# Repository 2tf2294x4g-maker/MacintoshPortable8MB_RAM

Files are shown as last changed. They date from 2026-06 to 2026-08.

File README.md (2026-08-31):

# Mac Portable 8MB RAM Card (v2 — All-5V)

Expands a Macintosh Portable to **9 MB total** (1 MB onboard + 8 MB this card) — the maximum the Portable's address space supports.

All-5V design using 1M×8 SRAM chips. No level shifters, no LDO regulator, no 3.3V rail. Shares the same connector, CPLD, and bus transceiver approach as the [4MB card](https://github.com/2tf2294x4g-maker/MacintoshPortable4MB_RAM) but doubles capacity using larger SRAM.

> ✅ **HARDWARE VALIDATED** — Built and tested on a Mac Portable M5120 (July 2026). Boots reliably, passes 9 MB in About This Macintosh, and with the DTACK bodge (see below) outperforms the 1 MB baseline.

---

## Photos

| | |
|---|---|
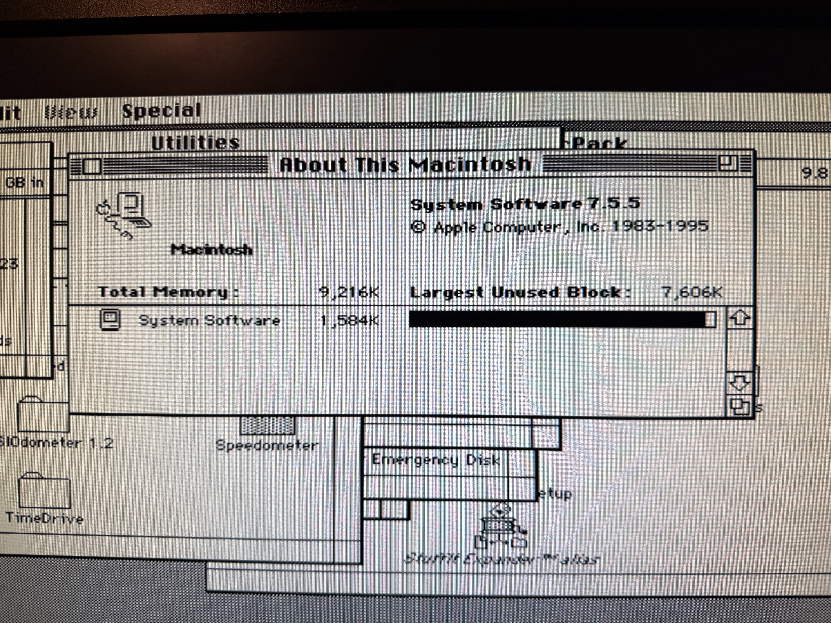
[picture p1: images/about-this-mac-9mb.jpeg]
About This Macintosh showing 9,216K
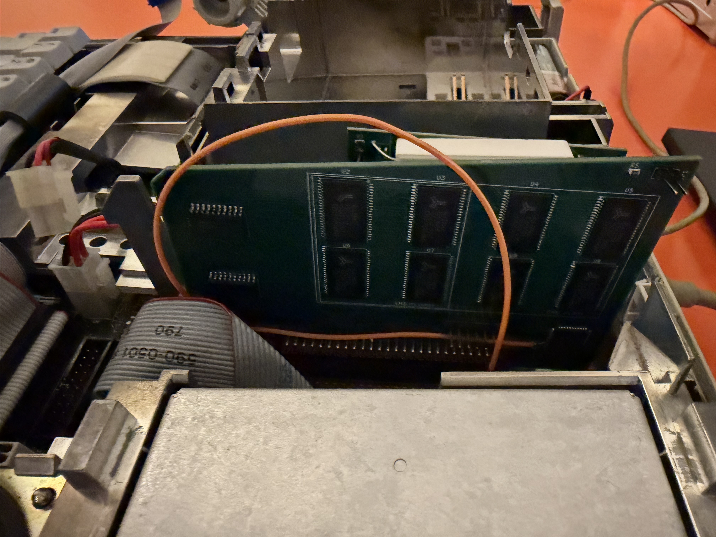
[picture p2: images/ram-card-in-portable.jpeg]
RAM card installed in Mac Portable with DTACK bodge wire
|  |  |
| System 7.5.5 — 9,216K total memory | Card seated in Portable with orange DTACK bodge wire |

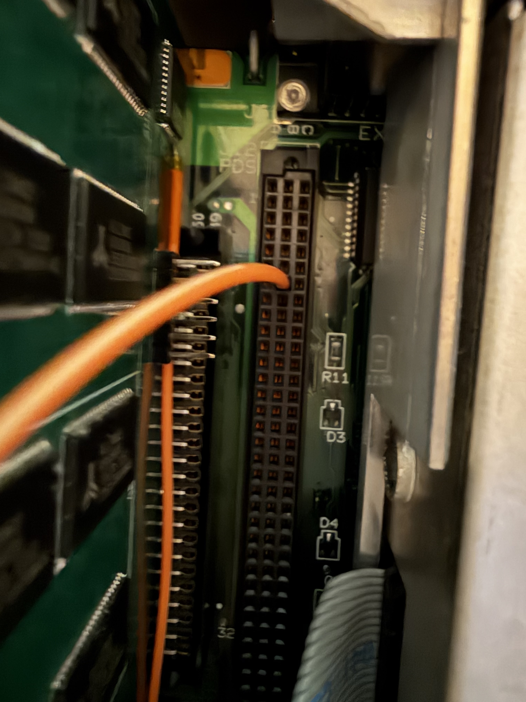
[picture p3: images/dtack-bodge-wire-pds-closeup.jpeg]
Close-up of DTACK bodge wire at PDS connector

*Orange bodge wire running from CPLD pin 42 to PDS slot pin B7 (/DTACK)*

| | |
|---|---|
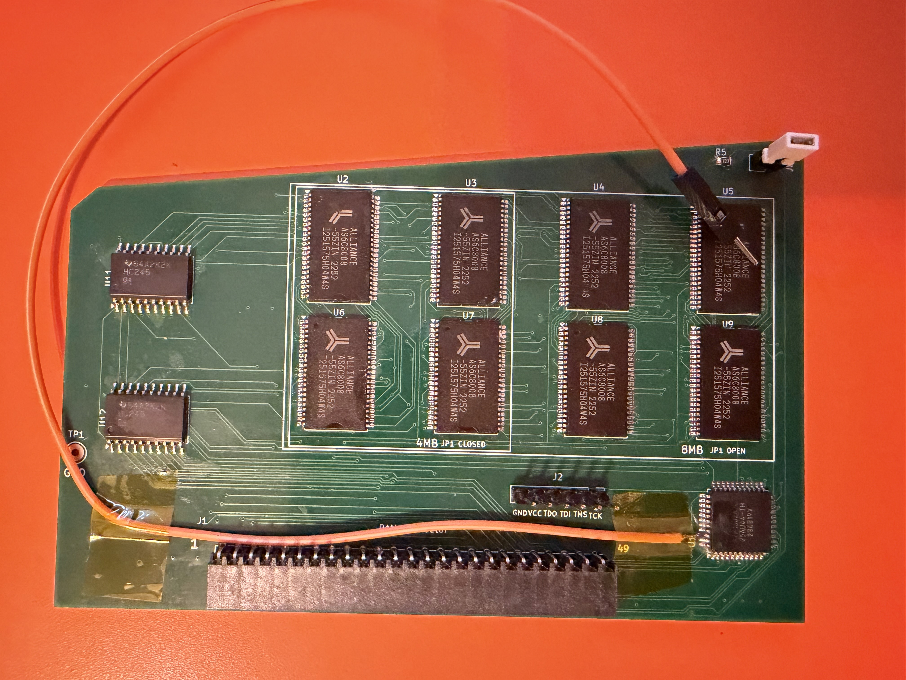
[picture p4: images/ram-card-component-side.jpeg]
Component side of assembled v2 card with DTACK bodge wire
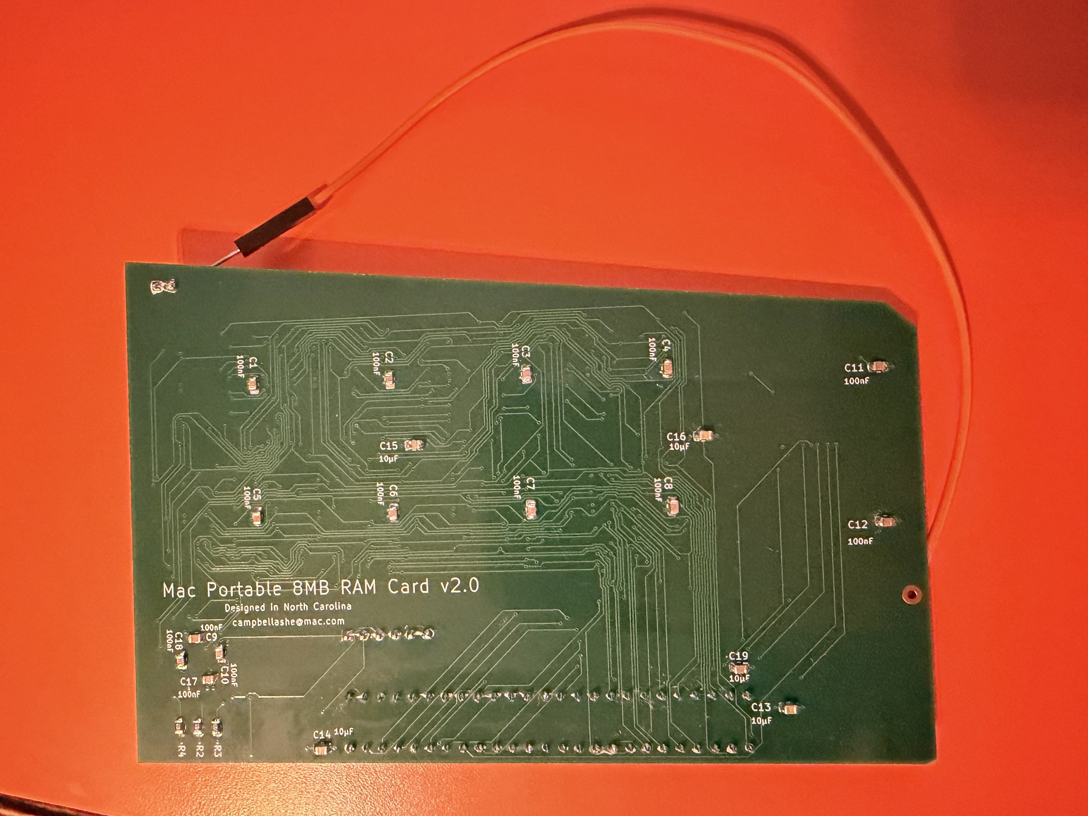
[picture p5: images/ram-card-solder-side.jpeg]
Solder side of assembled v2 card
|  |  |
| Component side — all 8 AS6C8008 SRAMs, bus transceivers, CPLD, and DTACK bodge wire | Solder side — bypass caps and bulk caps

---

## Specs

| | |
|---|---|
| Capacity | 8 MB (8× 1M×8 SRAM) |
| System total | 9 MB (1 MB onboard + 8 MB card) |
| Bus width | 8-bit × 2 banks (addressed via CPLD) |
| Logic | ATF1502ASL CPLD (5V, TQFP-44) |
| SRAM | 8× AS6C8008-55ZIN (5V, TSOP-II-44) |
| Layers | 4 (F.Cu signal / GND plane / +5V plane / B.Cu signal + pour) |
| Connector | Samtec BCS-125-F-D-HE (50-pin 2×25, horizontal entry) |
| Size jumper | JP1: OPEN = 8MB (all chips) / CLOSED = 4MB (populate U2 U3 U6 U7 only) |

---

## Bill of Materials

| Ref | Qty | Value | Package | Part / Notes |
|-----|----:|---|---|---|
| U2–U9 | 8 | AS6C8008-55ZIN | TSOP-II-44 | Alliance Memory — 1M×8 5V SRAM 55 ns |
| U1 | 1 | ATF1502ASL | TQFP-44 | Microchip ATF1502ASL-**25AU44** — must be ASL (5V), not ASV |
| U11, U12 | 2 | 74HC245 | SOIC-20 **wide** | SN74HC245**DW** — verify wide (7.5 mm) body |
| J1 | 1 | RAM connector | Samtec BCS-125-F-D-HE | 50-pin socket, horizontal entry — free Samtec sample |
| J2 | 1 | JTAG header | 1×6 2.54 mm pin header | Pin 1 (square pad) = TCK |
| JP1 | 1 | SIZE jumper | 1×2 2.54 mm pin header + shunt | OPEN=8MB, CLOSED=4MB |
| C1–C12, C17, C18 | 14 | 100 nF | 0805 | X7R 50V ceramic bypass |
| C13–C16, C19 | 5 | 10 µF | 0805 | X5R 16V ceramic bulk |
| R2–R5 | 4 | 10 KΩ | 0805 | 5% thick film |

Full BOM: [PortableRAM-8MB-BOM.csv](PortableRAM-8MB-BOM.csv)

---

## ⚠️ Important — SRAM Pinout Difference

The AS6C8008 (8MB card) and AS7C4096A (4MB card) are **both TSOP-II-44 but have different pinouts**. Do not install 4MB card SRAM chips on this board — the CE#, WE#, and OE# pins are in different locations and the board will not work correctly.

---

## Population Guide

The silkscreen shows two labeled boxes:

| Box | Chips | Config |
|-----|---|---|
| **4MB** | U2, U3, U6, U7 | JP1 CLOSED — populate these 4 chips only |
| **8MB ONLY** | U4, U5, U8, U9 | JP1 OPEN — populate all 8 chips |

For a full 8MB build, populate all 8 chips and leave JP1 open (no shunt).

---

## Files

```
PortableRAM-8MB.kicad_pcb     — PCB layout (KiCad 9)
PortableRAM-8MB.kicad_sch     — Schematic
PortableRAM-8MB.kicad_pro     — Project file
PortableRAM.kicad_sym         — Custom symbol library
PortableRAM.pretty/           — Custom footprint library
Gerbers/                      — Gerber + drill files (ready to order)
Gerbers.zip                   — Same, zipped (upload directly to fab)
firmware/
  PortableRAM8.pld            — CUPL source (ATF1502ASL logic)
  PortableRAM8.jed            — Compiled JEDEC
  PortableRAM8.svf            — SVF for OpenOCD programming
  program.sh                  — One-command programming script (Tigard)
  BUILD.md                    — Firmware build instructions (WinCUPL + Wine)
PortableRAM-8MB-BOM.csv
```

---

## Ordering the PCB

Upload `Gerbers.zip` to your preferred fab (JLCPCB, PCBWay, OSHPark, etc.).

**Board settings:**
- Layers: **4**
- Thickness: 1.6 mm
- Surface finish: **ENIG** (recommended — 0.8mm pitch fine-pitch pads benefit from the flat surface)
- All other settings: fab defaults

---

## Assembly Notes

Solder in this order:

1. **U1** (ATF1502ASL CPLD, TQFP-44) — centre first
2. **U2–U9** (SRAM, TSOP-II-44) — fine pitch; flux generously. See population guide above.
3. **U11, U12** (74HC245, SOIC-20 wide)
4. **C1–C18** (100 nF 0805 bypass caps)
5. **C13–C19** (10 µF 0805 bulk caps)
6. **R2–R5** (10 KΩ 0805)
7. **JP1** (1×2 header — leave open for 8MB, or install shunt for 4MB)
8. **J2** (1×6 JTAG header — before J1 for iron clearance)
9. **J1** (Samtec connector) — last

---

## Programming the CPLD

The ATF1502ASL must be programmed before the card will work. Use J2 (1×6 header on the board edge).

### J2 pinout (pin 1 = square pad)

| Pin | Signal |
|-----|---|
| 1 | TCK |
| 2 | TMS |
| 3 | TDI |
| 4 | TDO |
| 5 | +5V |
| 6 | GND |

### With a Tigard programmer (FT2232H-based)

Set the Tigard voltage jumper to **5V** before connecting.

```bash
cd firmware
./program.sh PortableRAM8.svf
```

Success output ends with `shutdown command invoked` and no TDO mismatch errors.

See [firmware/BUILD.md](firmware/BUILD.md) for full build and programming pipeline.

---

## Installation

1. Power off and unplug the Mac Portable.
2. Remove the battery and bottom cover.
3. Seat the card on the RAM expansion header — J1 is a friction-fit horizontal-entry socket.
4. Reassemble and power on.

You should see **9 MB** in About This Macintosh.

### DTACK Performance Fix (firmware rev 12)

The Mac Portable's GLU chip generates /DTACK for the 68000 with region-dependent timing:

| Address range | GLU /DTACK | Condition |
|---|---|---|
| 0x000000–0x4FFFFF | 2 clocks | Always — hardwired fast path |
| 0x500000–0x8FFFFF | 6 clocks | Normal operation (register configured) |
| 0x500000–0x8FFFFF | 18 clocks | After sleep/wake (register reset) |

The 8 MB card spans 0x100000–0x8FFFFF, straddling the split. Banks 0–1 (0x100000–0x4FFFFF) already get the GLU's 2-clock fast path. Banks 2–3 (0x500000–0x8FFFFF) run at 6 clocks and collapse to 18 clocks after sleep/wake when the GLU's DTACK register loses its configuration.

The fix: the ATF1502ASL CPLD now asserts /DTACK itself, via a bodge wire from CPLD pin 42 to PDS slot pin B7. The CPLD monitors the address bus and data strobes, and whenever a cycle falls within the card's memory window (0x100000–0x8FFFFF) it pulls /DTACK low directly — bypassing the GLU completely. The output is tristated for all other bus cycles so there's no contention.

Because the logic is purely combinatorial (no registers, no state), it's immune to sleep/wake — the CPLD re-evaluates every cycle from scratch. The post-sleep collapse is gone.

**Benchmark results (Speedometer 3.23 / Snooper Memory Move — System 7.1, M5120):**

| Configuration | Speedometer | Snooper | Post-sleep |
|---|---|---|---|
| 1 MB card (baseline) | 1.990 | 87% | 1.985 |
| 4 MB expansion card | 1.955 | 85% | — |
| 8 MB card — no DTACK bodge | 1.486 | 51% | — |
| 8 MB card — no bodge, after sleep | 0.974 | 22% | — |
| **8 MB card + CPLD DTACK bodge** | **2.170** | **102%** | **2.170** |
| **4 MB card + CPLD DTACK bodge** | **2.170** | **102%** | **2.170** |

The CPLD's combinatorial DTACK is faster than the GLU — the 8 MB card with the bodge outperforms the 1 MB baseline. Post-sleep performance is identical to cold boot. The 4 MB configuration with the DTACK bodge also scores 102%, confirming the CPLD path is faster than even the GLU's hardwired 2-clock mode for the lower address range.

**How to wire it:** Solder a bodge wire from CPLD pin 42 (U1, TQFP-44) to PDS slot pin B7 (/DTACK). The PDS connector is the 96-pin DIN-41612 on the Mac Portable motherboard (3 rows A/B/C, 32 pins each). Pin B7 is in row B, position 7 from the component side.

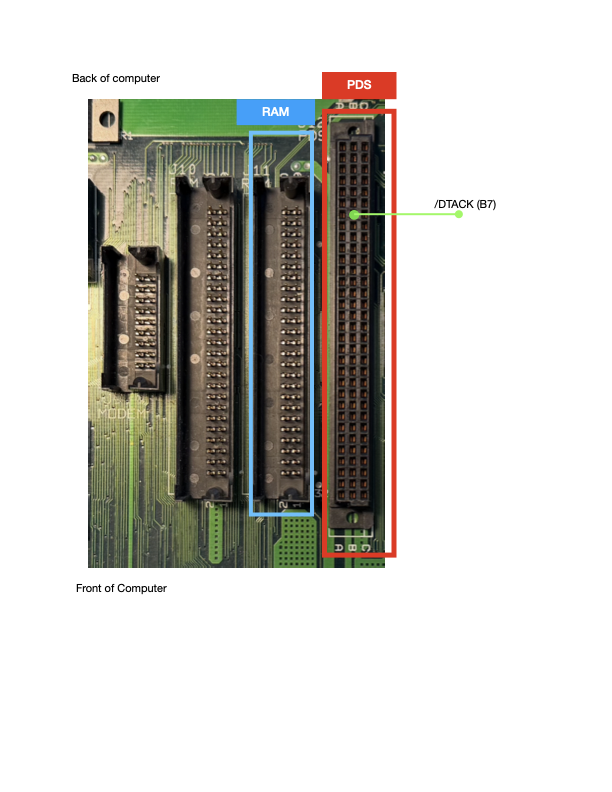
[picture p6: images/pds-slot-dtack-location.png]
PDS slot and RAM connector locations, with /DTACK (B7) marked


---

## Cost

### PCB — JLCPCB (July 2026)

| | |
|---|---|
| 5× 4-layer boards (ENIG) | $48.70 |
| Shipping | $8.79 |
| Discount | −$5.49 |
| Tax | $3.68 |
| Payment fee | $0.52 |
| **Total for 5 boards** | **$56.20** |
| **Per board** | **~$11.24** |

ENIG finish recommended over HASL for the 0.8mm pitch TSOP-II-44 and TQFP-44 pads.

### Parts — DigiKey

| Part | Qty | Unit | Ext |
|---|----:|-----:|----:|
| ATF1502ASL-25AU44 (CPLD) | 1 | $3.12 | $3.12 |
| SN74HC245DWR (74HC245 wide SOIC) | 2 | $0.75 | $1.50 |
| 100 nF 50V X7R 0805 | 14 | $0.07 | $0.98 |
| 10 µF 16V X5R 0805 | 5 | $0.46 | $2.30 |
| 10 KΩ 5% 0805 | 4 | $0.03 | $0.12 |

### Parts — DigiKey (SRAM)

| Part | Qty | Unit | Ext |
|---|----:|-----:|----:|
| AS6C8008-55ZIN (1M×8 5V SRAM) | 10 | ~$10.17 | ~$102 |

Order 10 (8 needed + 2 spares).

### Samtec J1 Connector

Free sample from samtec.com (BCS-125-F-D-HE). Allow 1–2 weeks.

### Summary — one board from scratch

| Item | Approx cost |
|---|---|
| PCB (1 of 5 from JLCPCB, ENIG) | $11 |
| 8× AS6C8008-55ZIN SRAM | $86 |
| CPLD + transceivers + passives | $8 |
| Samtec J1 | free / ~$10 |
| **Total** | **~$105–115** |

The SRAM dominates the cost. Compared to the 4MB card (~$93–103), the extra cost is the larger SRAM chips and ENIG finish.

---

## References & Acknowledgements

This card would not exist without the following prior work:

**Dynamic Engineering Mac Portable RAM Card**
The address decode and bus control logic in `PortableRAM8.pld` is derived from the GAL22V10 PLD source files originally written for the Dynamic Engineering commercial RAM expansion card for the Mac Portable. These files define the core signal equations — bank chip-select generation, byte-lane write control via UDS*/LDS*, bus transceiver direction, and output enable timing. The original `.PLD` files were recovered and shared by *techknight* on the TinkerDifferent forum and #skunkworks Discord. Translated here from three GAL22V10 chips to a single ATF1502ASL CPLD, with corrections to the `r_w_u` equation and address decode base, and extended for 8MB capacity.

**miejas — Macintosh Portable 4MB Memory Expansion**
[https://github.com/miejas/Macintosh-Portable-4-MB-Memory-Expansion](https://github.com/miejas/Macintosh-Portable-4-MB-Memory-Expansion)
Open-source 4MB RAM card whose connector pinout, bus transceiver approach, and firmware structure were used as a cross-reference to validate signal assignments and confirm that AS* and SLEEP* are not present on the expansion connector.

**Reza Fouladian — PortableRAM BGA 8MB**
[https://github.com/rezafouladian/PortableRAM-BGA-8MB](https://github.com/rezafouladian/PortableRAM-BGA-8MB)
BGA-format 8MB card using the ATF1502ASV (3.3V CPLD) and SN74LVC4245A level translators. Used as a reference for the 8MB address decode strategy and CPLD pin planning. Reza also provided direct guidance on driving /DTACK from the CPLD and on the Mac Portable PDS connector pinout — specifically confirming that /DTACK is available on PDS pin B7 and can be driven directly from a CPLD output, which was the key insight that led to the DTACK bodge fix implemented in firmware rev 12. That fix eliminated the GLU wait-state penalty and the post-sleep performance collapse entirely.

**Apple Mac Portable Developer Notes & Schematics**
Apple's original hardware documentation for the Mac Portable expansion bus, memory map, and GLU register behaviour (including the $FC0200 DTACK register).

---

## License

- **Hardware** (schematics, PCB layout, Gerbers) — [CERN-OHL-S v2](LICENSE) · SPDX `CERN-OHL-S-2.0`
- **Firmware source** (`PortableRAM8.pld`) — [MIT](LICENSE-MIT) · SPDX `MIT`

Both licence texts are included in full in this repository.
Do what you like — just share improvements.

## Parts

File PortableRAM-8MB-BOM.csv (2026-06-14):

Ref | Qty | Value | Package | Manufacturer | Mfr Part Number | Notes
U2-U9 | 8 | AS6C8008-55ZIN | TSOP-II-44 (10.16x18.41mm P0.8mm) | Alliance Memory | AS6C8008-55ZIN | 1Mx8 SRAM 5V 55ns (Z=TSOP-II pkg); ~$13-15 each; order 1-2 spares; 8 chips = 8MB
U1 | 1 | ATF1502ASL | TQFP-44 (10x10mm P0.8mm) | Microchip | ATF1502ASL-25AU44 | 5V CPLD (ASL = 5V; do NOT order ASV which is 3.3V); needs JTAG programming; order a spare
U11 U12 | 2 | 74HC245 | SOIC-20W (7.5mm wide) | TI/Nexperia | SN74HC245DW | Octal bus transceiver 5V; verify WIDE SOIC-20 body (DW/DWR suffix)
J1 | 1 | RAM Connector | Samtec BCS-125-F-D-HE | Samtec | BCS-125-F-D-HE | 50-pin 2x25 2.54mm socket strip; footprint verified vs drawing
J2 | 1 | JTAG Header 1x06 | PinHeader 2.54mm 1x06 vertical | Generic |  | Standard 0.1in header for CPLD JTAG programming
JP1 | 1 | SIZE jumper 1x02 | PinHeader 2.54mm 1x02 vertical | Generic |  | Size select: OPEN=8MB (all 8 SRAMs) / CLOSED=4MB (populate U2 U3 U6 U7 only). Add one 2.54mm shunt.
C1-C12 C17 C18 | 14 | 100nF | 0805 (2012 metric) | Generic |  | X7R 50V ceramic; one per chip + per CPLD VCC pin; buy strip of 50+
C13-C16 C19 | 5 | 10uF | 0805 (2012 metric) | Generic |  | X5R 16V ceramic bulk; C19 at J1 power entry; buy 10+
R2-R5 | 4 | 10K | 0805 (2012 metric) | Generic |  | 5% thick film pull-ups (R5 = SIZE8 jumper pull-up to +5V); buy strip

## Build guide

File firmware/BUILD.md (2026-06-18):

# CPLD Firmware Build — CUPL toolchain (Mac + Linux server)

WinCUPL is Windows-only, so we compile on the Ubuntu server under Wine.
Applies to both PortableRAM.pld (v0.2 4MB) and PortableRAM8.pld (v2 8MB).

## Where it's set up (server 192.168.0.52)
- Wine prefix: `~/.wine-cupl` (WINEARCH=win32) with WinCUPL installed at `C:\Wincupl`
- Fitters upgraded to **v1918** (from Atmel ProChip 5.0.1) in `C:\Wincupl\WinCupl\Fitters`
- `5vcomp` wrapper (from github peterzieba/5Vpld) at `/usr/local/bin/5vcomp`
- Working dir: `~/cupl-build`

## To compile
```
scp firmware/PortableRAM.pld matthew@192.168.0.52:~/cupl-build/
ssh matthew@192.168.0.52 'cd cupl-build; WINEPREFIX=$HOME/.wine-cupl xvfb-run -a 5vcomp PortableRAM.pld'
scp matthew@192.168.0.52:~/cupl-build/PortableRAM.jed firmware/
```
Outputs: `.jed` (program this), `.fit` (CHECK pin assignments + "JTAG = ON"), `.err`.

## .PLD source rules (CUPL is picky — these caused real failures)
1. **Pure ASCII only** — no em-dashes (—), smart quotes, etc. CUPL chokes on UTF-8.
2. **CRLF line endings** — LF-only makes the cuplx preprocessor abort.
3. **No `*/` inside comments** — e.g. write `UDS*, LDS*` NOT `UDS*/LDS*`; the `*/`
   closes the C-style comment early and the rest parses as code.
4. **`PROPERTY ATMEL { jtag = on };`** — keeps JTAG pins live so the Tigard can
   re-program. (Default is ON for the ispTQFP44 device, but be explicit.)

## JED -> SVF (DONE — cross-platform, on the Mac, no Wine)
Uses fuseconv from whitequark/prjbureau (pure Python):
```
pip3 install --user bitarray
git clone https://github.com/whitequark/prjbureau   # has util/fuseconv.py
cd prjbureau && python3 -m util.fuseconv -d ATF1502AS <in>.jed <out>.svf
```
The .svf self-verifies (includes readback vectors). ATF1502AS: IR length 10,
IDCODE 0x0150203f.

## Programming (when boards arrive) — Tigard + OpenOCD, on the Mac
1. `brew install open-ocd`
2. Wire Tigard JTAG to J2: TDI=pin1, TMS=pin7, TCK=pin26, TDO=pin32 (+GND, +5V sense).
3. Power the board (5V).
4. Run the bundled script:  `./program.sh PortableRAM8.svf`
   (wraps: openocd -f interface/ftdi/tigard.cfg, jtag newtap -irlen 10
    -expected-id 0x0150203f, svf <file>)

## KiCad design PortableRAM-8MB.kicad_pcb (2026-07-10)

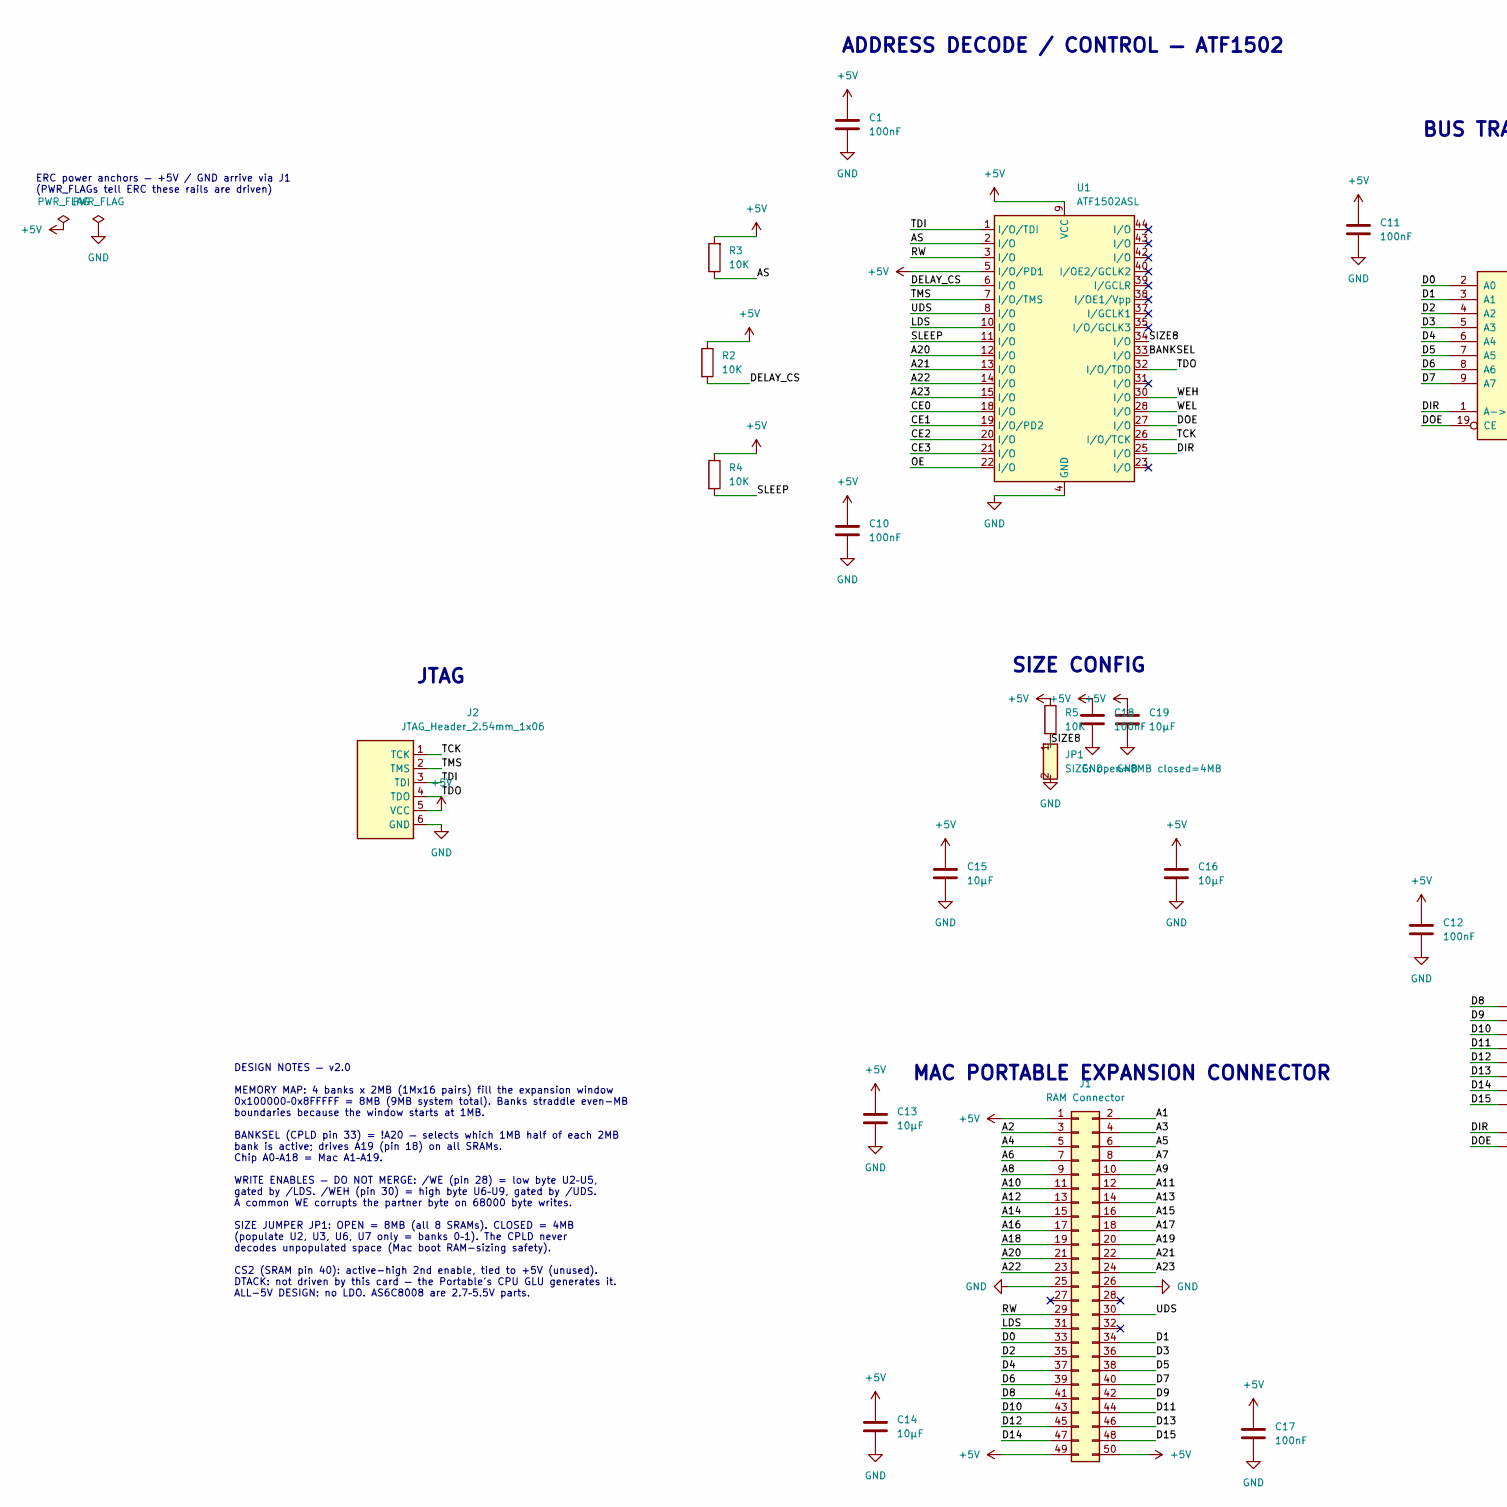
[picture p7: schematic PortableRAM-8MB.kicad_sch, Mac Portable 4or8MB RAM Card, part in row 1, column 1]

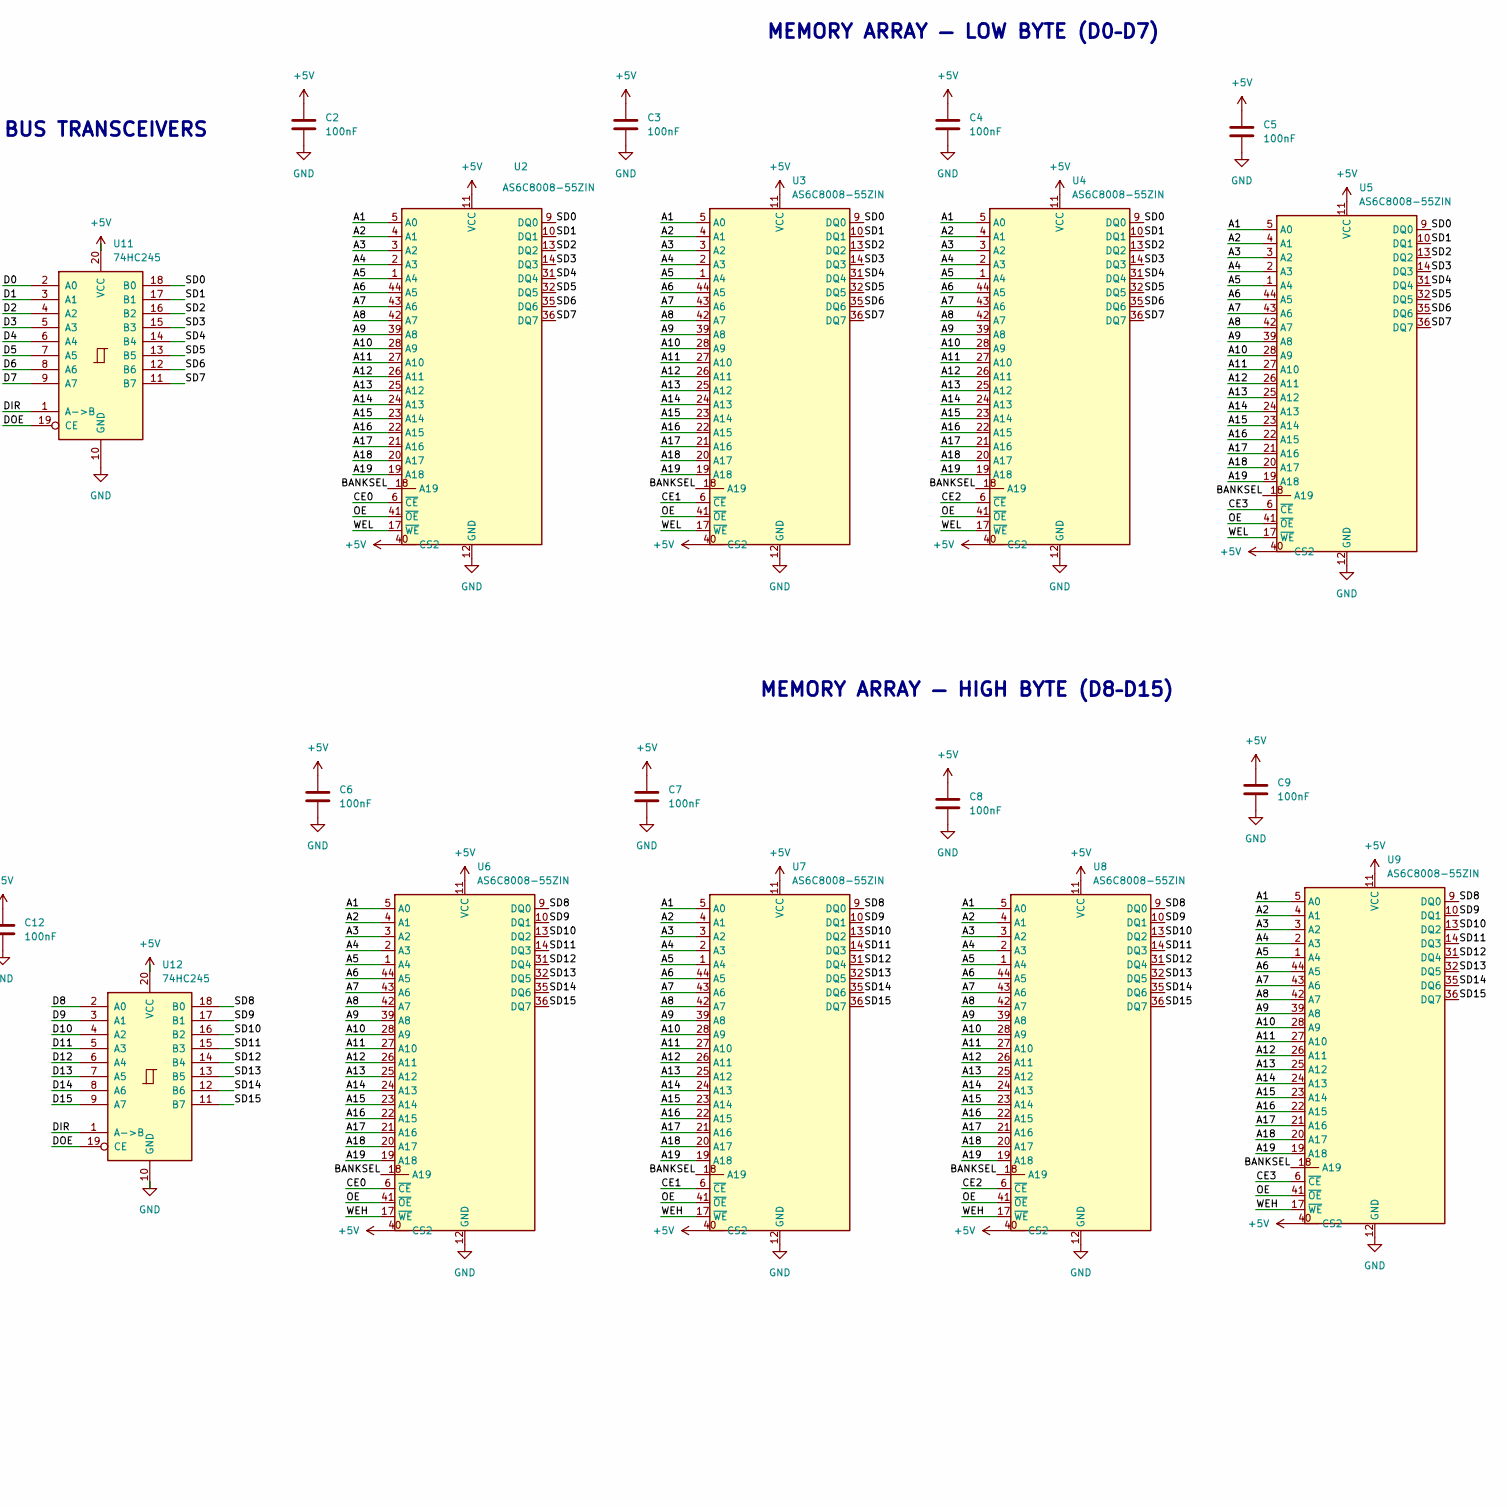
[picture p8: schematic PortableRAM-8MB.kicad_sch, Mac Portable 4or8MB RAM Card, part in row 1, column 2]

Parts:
C1, C2, C3, C4, C5, C6, C7, C8, C9, C10, C11, C12, C17, C18: 100nF; C_0805_2012Metric
C13, C14, C15, C16, C19: 10µF; C_0805_2012Metric
J1: RAM Connector; Samtec_BCS-125-F-D-HE
J2: JTAG_Header_2.54mm_1x06; PinHeader_1x06_P2.54mm_Vertical
JP1: SIZE: open=8MB closed=4MB; PinHeader_1x02_P2.54mm_Vertical
R2, R3, R4, R5: 10K; R_0805_2012Metric
U1: ATF1502ASL; TQFP-44_10x10mm_P0.8mm
U2, U3, U4, U5, U6, U7, U8, U9: AS6C8008-55ZIN; TSOP-II-44_10.16x18.41mm_P0.8mm
U11, U12: 74HC245; SOIC-20W_7.5x12.8mm_P1.27mm

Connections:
+5V: C1.1, C2.1, C3.1, C4.1, C5.1, C6.1, C7.1, C8.1, C9.1, C10.1, C11.1, C12.1, C13.1, C14.1, C15.1, C16.1, C17.1, C18.1, C19.1, J1.1, J1.49, J1.50, J2.5 (VCC), R2.1, R3.2, R4.1, R5.1, U1.5 (I/O/PD1), U1.9 (VCC), U1.17 (VCC), U1.29 (VCC), U1.41 (VCC), U2.11 (VCC), U2.33 (VCC), U2.40 (CS2), U3.11 (VCC), U3.33 (VCC), U3.40 (CS2), U4.11 (VCC), U4.33 (VCC), U4.40 (CS2), U5.11 (VCC), U5.33 (VCC), U5.40 (CS2), U6.11 (VCC), U6.33 (VCC), U6.40 (CS2), U7.11 (VCC), U7.33 (VCC), U7.40 (CS2), U8.11 (VCC), U8.33 (VCC), U8.40 (CS2), U9.11 (VCC), U9.33 (VCC), U9.40 (CS2), U11.20 (VCC), U12.20 (VCC)
/A1: J1.2, U2.5 (A0), U3.5 (A0), U4.5 (A0), U5.5 (A0), U6.5 (A0), U7.5 (A0), U8.5 (A0), U9.5 (A0)
/A2: J1.3, U2.4 (A1), U3.4 (A1), U4.4 (A1), U5.4 (A1), U6.4 (A1), U7.4 (A1), U8.4 (A1), U9.4 (A1)
/A3: J1.4, U2.3 (A2), U3.3 (A2), U4.3 (A2), U5.3 (A2), U6.3 (A2), U7.3 (A2), U8.3 (A2), U9.3 (A2)
/A4: J1.5, U2.2 (A3), U3.2 (A3), U4.2 (A3), U5.2 (A3), U6.2 (A3), U7.2 (A3), U8.2 (A3), U9.2 (A3)
/A5: J1.6, U2.1 (A4), U3.1 (A4), U4.1 (A4), U5.1 (A4), U6.1 (A4), U7.1 (A4), U8.1 (A4), U9.1 (A4)
/A6: J1.7, U2.44 (A5), U3.44 (A5), U4.44 (A5), U5.44 (A5), U6.44 (A5), U7.44 (A5), U8.44 (A5), U9.44 (A5)
/A7: J1.8, U2.43 (A6), U3.43 (A6), U4.43 (A6), U5.43 (A6), U6.43 (A6), U7.43 (A6), U8.43 (A6), U9.43 (A6)
/A8: J1.9, U2.42 (A7), U3.42 (A7), U4.42 (A7), U5.42 (A7), U6.42 (A7), U7.42 (A7), U8.42 (A7), U9.42 (A7)
/A9: J1.10, U2.39 (A8), U3.39 (A8), U4.39 (A8), U5.39 (A8), U6.39 (A8), U7.39 (A8), U8.39 (A8), U9.39 (A8)
/A10: J1.11, U2.28 (A9), U3.28 (A9), U4.28 (A9), U5.28 (A9), U6.28 (A9), U7.28 (A9), U8.28 (A9), U9.28 (A9)
/A11: J1.12, U2.27 (A10), U3.27 (A10), U4.27 (A10), U5.27 (A10), U6.27 (A10), U7.27 (A10), U8.27 (A10), U9.27 (A10)
/A12: J1.13, U2.26 (A11), U3.26 (A11), U4.26 (A11), U5.26 (A11), U6.26 (A11), U7.26 (A11), U8.26 (A11), U9.26 (A11)
/A13: J1.14, U2.25 (A12), U3.25 (A12), U4.25 (A12), U5.25 (A12), U6.25 (A12), U7.25 (A12), U8.25 (A12), U9.25 (A12)
/A14: J1.15, U2.24 (A13), U3.24 (A13), U4.24 (A13), U5.24 (A13), U6.24 (A13), U7.24 (A13), U8.24 (A13), U9.24 (A13)
/A15: J1.16, U2.23 (A14), U3.23 (A14), U4.23 (A14), U5.23 (A14), U6.23 (A14), U7.23 (A14), U8.23 (A14), U9.23 (A14)
/A16: J1.17, U2.22 (A15), U3.22 (A15), U4.22 (A15), U5.22 (A15), U6.22 (A15), U7.22 (A15), U8.22 (A15), U9.22 (A15)
/A17: J1.18, U2.21 (A16), U3.21 (A16), U4.21 (A16), U5.21 (A16), U6.21 (A16), U7.21 (A16), U8.21 (A16), U9.21 (A16)
/A18: J1.19, U2.20 (A17), U3.20 (A17), U4.20 (A17), U5.20 (A17), U6.20 (A17), U7.20 (A17), U8.20 (A17), U9.20 (A17)
/A19: J1.20, U2.19 (A18), U3.19 (A18), U4.19 (A18), U5.19 (A18), U6.19 (A18), U7.19 (A18), U8.19 (A18), U9.19 (A18)
/A20: J1.21, U1.12 (I/O)
/A21: J1.22, U1.13 (I/O)
/A22: J1.23, U1.14 (I/O)
/A23: J1.24, U1.15 (I/O)
/AS: R3.1, U1.2 (I/O)
/BANKSEL: U1.33 (I/O), U2.18 (A19), U3.18 (A19), U4.18 (A19), U5.18 (A19), U6.18 (A19), U7.18 (A19), U8.18 (A19), U9.18 (A19)
/CE0: U1.18 (I/O), U2.6 (~CE), U6.6 (~CE)
/CE1: U1.19 (I/O/PD2), U3.6 (~CE), U7.6 (~CE)
/CE2: U1.20 (I/O), U4.6 (~CE), U8.6 (~CE)
/CE3: U1.21 (I/O), U5.6 (~CE), U9.6 (~CE)
/D0: J1.33, U11.2 (A0)
/D1: J1.34, U11.3 (A1)
/D2: J1.35, U11.4 (A2)
/D3: J1.36, U11.5 (A3)
/D4: J1.37, U11.6 (A4)
/D5: J1.38, U11.7 (A5)
/D6: J1.39, U11.8 (A6)
/D7: J1.40, U11.9 (A7)
/D8: J1.41, U12.2 (A0)
/D9: J1.42, U12.3 (A1)
/D10: J1.43, U12.4 (A2)
/D11: J1.44, U12.5 (A3)
/D12: J1.45, U12.6 (A4)
/D13: J1.46, U12.7 (A5)
/D14: J1.47, U12.8 (A6)
/D15: J1.48, U12.9 (A7)
/DELAY_CS: R2.2, U1.6 (I/O)
/DIR: U1.25 (I/O), U11.1 (A->B), U12.1 (A->B)
/DOE: U1.27 (I/O), U11.19 (CE), U12.19 (CE)
/LDS: J1.31, U1.10 (I/O)
/OE: U1.22 (I/O), U2.41 (~OE), U3.41 (~OE), U4.41 (~OE), U5.41 (~OE), U6.41 (~OE), U7.41 (~OE), U8.41 (~OE), U9.41 (~OE)
/RW: J1.29, U1.3 (I/O)
/SD0: U2.9 (DQ0), U3.9 (DQ0), U4.9 (DQ0), U5.9 (DQ0), U11.18 (B0)
/SD1: U2.10 (DQ1), U3.10 (DQ1), U4.10 (DQ1), U5.10 (DQ1), U11.17 (B1)
/SD2: U2.13 (DQ2), U3.13 (DQ2), U4.13 (DQ2), U5.13 (DQ2), U11.16 (B2)
/SD3: U2.14 (DQ3), U3.14 (DQ3), U4.14 (DQ3), U5.14 (DQ3), U11.15 (B3)
/SD4: U2.31 (DQ4), U3.31 (DQ4), U4.31 (DQ4), U5.31 (DQ4), U11.14 (B4)
/SD5: U2.32 (DQ5), U3.32 (DQ5), U4.32 (DQ5), U5.32 (DQ5), U11.13 (B5)
/SD6: U2.35 (DQ6), U3.35 (DQ6), U4.35 (DQ6), U5.35 (DQ6), U11.12 (B6)
/SD7: U2.36 (DQ7), U3.36 (DQ7), U4.36 (DQ7), U5.36 (DQ7), U11.11 (B7)
/SD8: U6.9 (DQ0), U7.9 (DQ0), U8.9 (DQ0), U9.9 (DQ0), U12.18 (B0)
/SD9: U6.10 (DQ1), U7.10 (DQ1), U8.10 (DQ1), U9.10 (DQ1), U12.17 (B1)
/SD10: U6.13 (DQ2), U7.13 (DQ2), U8.13 (DQ2), U9.13 (DQ2), U12.16 (B2)
/SD11: U6.14 (DQ3), U7.14 (DQ3), U8.14 (DQ3), U9.14 (DQ3), U12.15 (B3)
/SD12: U6.31 (DQ4), U7.31 (DQ4), U8.31 (DQ4), U9.31 (DQ4), U12.14 (B4)
/SD13: U6.32 (DQ5), U7.32 (DQ5), U8.32 (DQ5), U9.32 (DQ5), U12.13 (B5)
/SD14: U6.35 (DQ6), U7.35 (DQ6), U8.35 (DQ6), U9.35 (DQ6), U12.12 (B6)
/SD15: U6.36 (DQ7), U7.36 (DQ7), U8.36 (DQ7), U9.36 (DQ7), U12.11 (B7)
/SIZE8: JP1.1, R5.2, U1.34 (I/O)
/SLEEP: R4.2, U1.11 (I/O)
/TCK: J2.1 (TCK), U1.26 (I/O/TCK)
/TDI: J2.3 (TDI), U1.1 (I/O/TDI)
/TDO: J2.4 (TDO), U1.32 (I/O/TDO)
/TMS: J2.2 (TMS), U1.7 (I/O/TMS)
/UDS: J1.30, U1.8 (I/O)
/WEH: U1.30 (I/O), U6.17 (~WE), U7.17 (~WE), U8.17 (~WE), U9.17 (~WE)
/WEL: U1.28 (I/O), U2.17 (~WE), U3.17 (~WE), U4.17 (~WE), U5.17 (~WE)
GND: C1.2, C2.2, C3.2, C4.2, C5.2, C6.2, C7.2, C8.2, C9.2, C10.2, C11.2, C12.2, C13.2, C14.2, C15.2, C16.2, C17.2, C18.2, C19.2, J1.25, J1.26, J2.6 (GND), JP1.2, U1.4 (GND), U1.16 (GND), U1.24 (GND), U1.36 (GND), U2.12 (GND), U2.34 (GND), U3.12 (GND), U3.34 (GND), U4.12 (GND), U4.34 (GND), U5.12 (GND), U5.34 (GND), U6.12 (GND), U6.34 (GND), U7.12 (GND), U7.34 (GND), U8.12 (GND), U8.34 (GND), U9.12 (GND), U9.34 (GND), U11.10 (GND), U12.10 (GND); also elsewhere on the board

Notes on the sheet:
ERC power anchors — +5V / GND arrive via J1 (PWR_FLAGs tell ERC these rails are driven)
JTAG
MAC PORTABLE EXPANSION CONNECTOR
ADDRESS DECODE / CONTROL — ATF1502
BUS TRANSCEIVERS
MEMORY ARRAY — LOW BYTE (D0–D7)
DESIGN NOTES — v2.0 MEMORY MAP: 4 banks x 2MB (1Mx16 pairs) fill the expansion window 0x100000–0x8FFFFF = 8MB (9MB system total). Banks straddle even-MB boundaries because the window starts at 1MB. BANKSEL (CPLD pin 33) = !A20 — selects which 1MB half of each 2MB bank is active; drives A19 (pin 18)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
MEMORY ARRAY — HIGH BYTE (D8–D15)
SIZE CONFIG

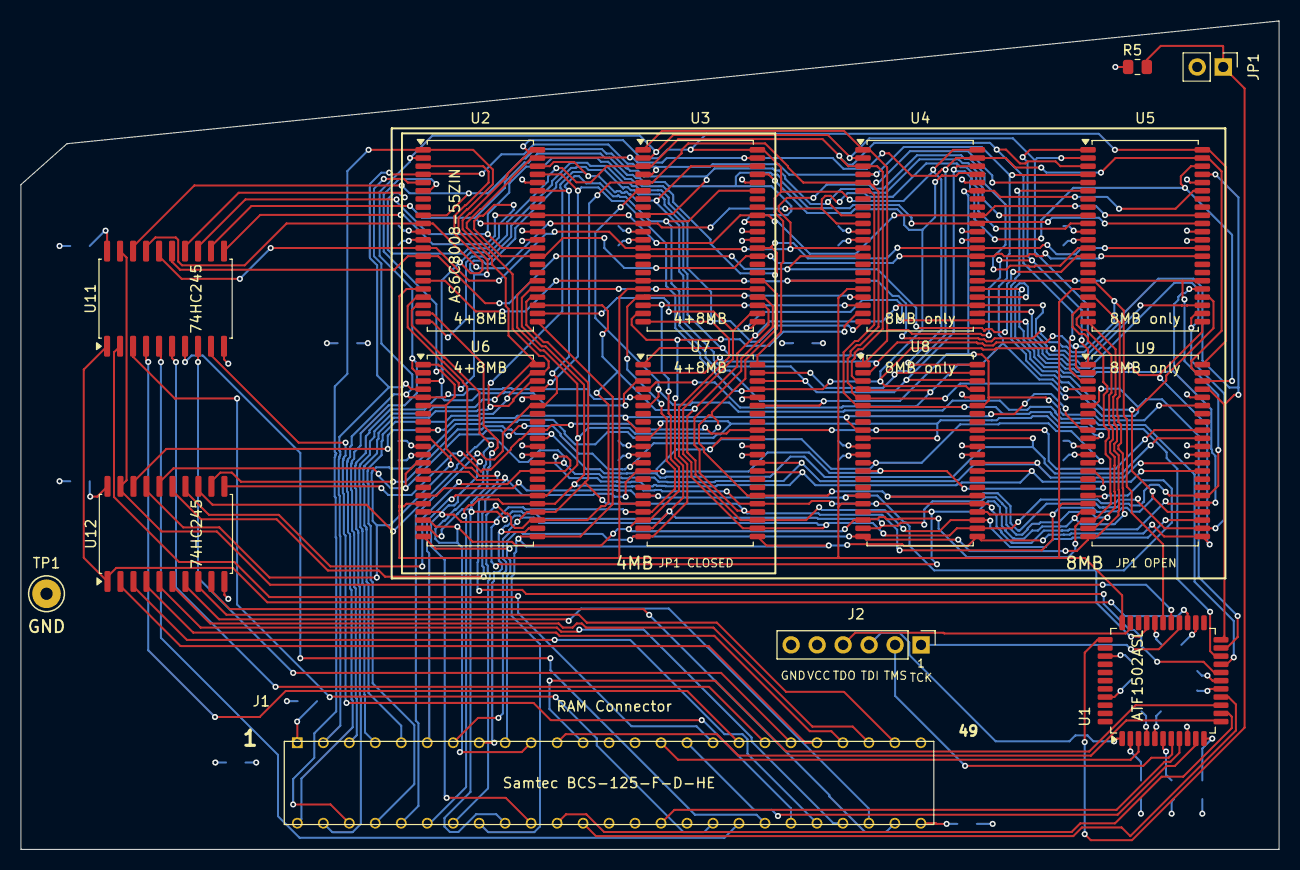
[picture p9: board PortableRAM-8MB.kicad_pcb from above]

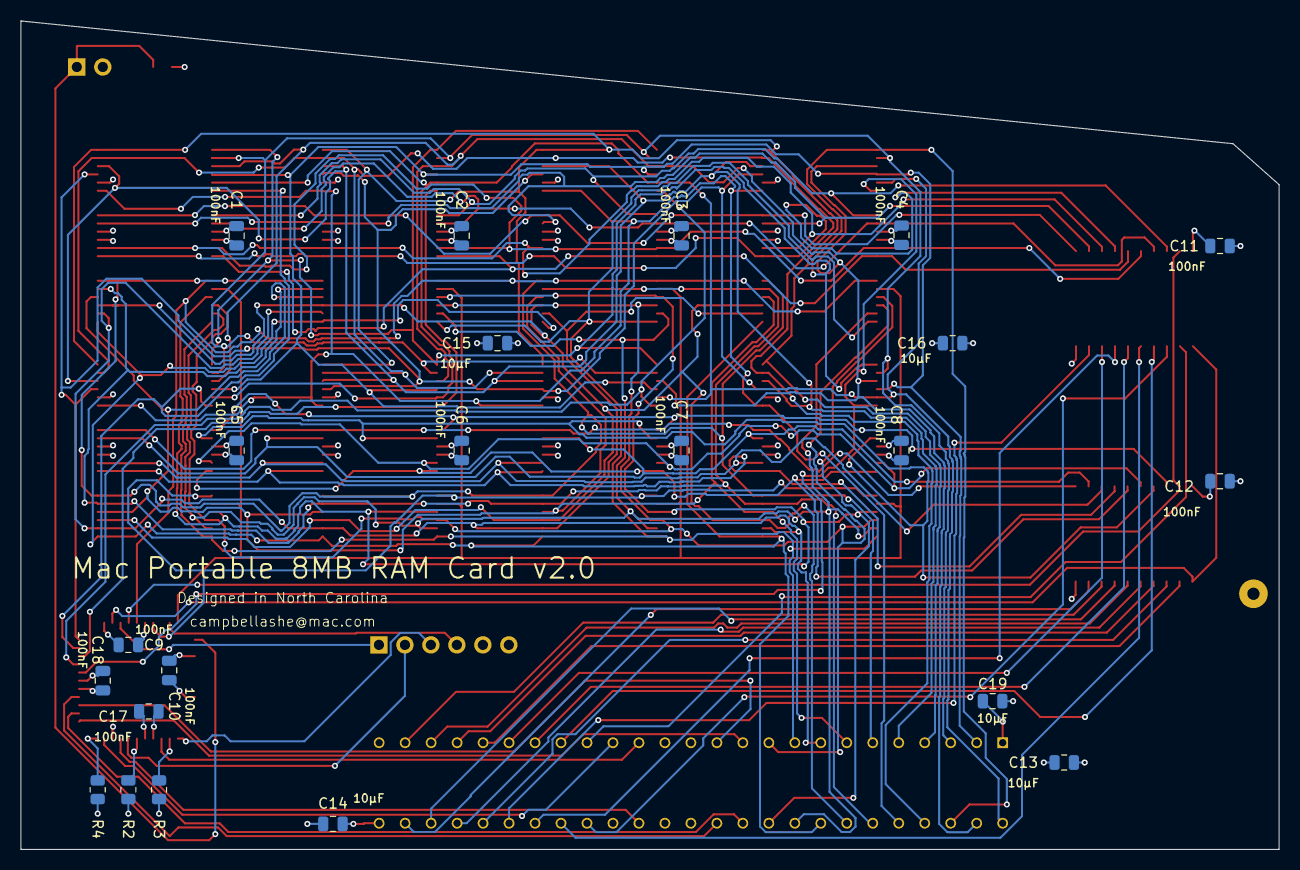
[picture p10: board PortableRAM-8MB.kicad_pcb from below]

Board: 4 copper layers, 123.0 x 81.0 mm, 38 parts (22 on the bottom side), 78 nets.

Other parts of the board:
TP1: GND; TestPoint_GND

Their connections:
GND: TP1.1; also elsewhere on the board

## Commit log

2026-06-12 Initial commit: v2.0-dev baseline from working 4MB v0.2 design
    Starting point for the 8MB all-5V redesign:
    - Project copied from PortableRAM-4MB v0.2 (the revision released to fab)
    - Firmware already reworked for 8MB: 1MB-page decode into 4 banks of
    2MB (1Mx16 AS6C8008 pairs), new A19RAM output (CPLD pin 33) = !A20
    - Schematic/PCB still carry the v0.2 4MB design; pending work:
    all-5V power (remove LDO + 3.3V rail), AS6C8008 symbol swap with
    CE2 (pin 40) tied high and A19 (pin 18) on A19RAM, In2 plane to +5V,
    SRAM region re-route
    [PortableRAM-8MB.kicad_pcb, PortableRAM-8MB.kicad_sch]
2026-06-12 Schematic: all-5V conversion + AS6C8008 (1Mx8) memory swap
    - All +3.3V power symbols converted to +5V; AMS1117 LDO (U10) and its
    rail markers/stub wires removed — single 5V domain
    - SRAM symbol renumbered in place to the AS6C8008 TSOP-II-44 pinout
    (graphics, wires, and labels untouched); pins 33/34 kept as VCC/GND
    rail ties (NC on the chip, preserves board plane stitching)
    - New pins: A19 (18) labeled A19RAM on all 8 chips, driven by CPLD
    pin 33; CE2 (40) tied to +5V via power symbols
    - PortableRAM.kicad_sym updated: AS6C8008 replaces IS61WV5128BLL
    - ERC: no new issues vs v0.2 baseline (PWR_FLAG/VCC-alias warnings
    and prior exclusions remain)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
    [PortableRAM-8MB.kicad_sch]
2026-06-12 Add SIZE jumper: one board, 4MB or 8MB by population
    - JP1 (1x02 header) + R5 10K pull-up on CPLD pin 34 (SIZE8), placed in
    the old LDO area; project-local Jumper_1x02 symbol added to library
    - Firmware: banks 2-3 and their address window gated by SIZE8 — jumper
    open = 8MB (8 chips), closed = 4MB (populate U2/U3/U6/U7, banks 0-1).
    Unpopulated space is never decoded, keeping the Mac's boot-time RAM
    sizing away from floating-bus false positives
    - Verified WE split intact after the AS6C8008 renumbering: /WE -> pin 28
    + U2-U5 pad 17, /WEH -> pin 30 + U6-U9 pad 17; firmware gates writes
    per byte lane (WEL&LDS / WEH&UDS)
    - ERC: 0 errors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
    [PortableRAM-8MB.kicad_sch]
2026-06-12 Rename A19RAM -> BANKSEL
    Clearer name for the CPLD-computed signal (= !A20) that selects which
    1MB half of each 2MB bank is active; avoids visual collision with the
    Mac /A19 address net on the schematic.
    [PortableRAM-8MB.kicad_sch]
2026-06-12 Add C18 (100nF, 4th CPLD VCC pin) and C19 (10uF, power-entry bulk)
    Decoupling now: one 100nF per AS6C8008 (8) + one per ATF1502 VCC pin (4)
    + one per 74HC245 (2) = 14, plus 5x 10uF bulk. C19 kept at 10uF to match
    purchased stock. Place C19 adjacent to J1 VCC pins at layout time.
    [PortableRAM-8MB.kicad_sch]
2026-06-12 Rename AS6C8008 symbol pin CE2 -> CS2 (cosmetic)
    Breaks the visual collision with the CE2 bank-select net on U4/U8.
    Pin function unchanged: active-high second chip enable, tied to +5V
    on all chips. Pad number stays 40.
    [PortableRAM-8MB.kicad_sch]
2026-06-12 Remove dead symbols from project library
    Deleted unused legacy symbols: 74AVCT16245 and ATF1502ASL (both had
    known-wrong pinouts from early design), AMS1117-3.3 (no LDO in v2),
    PortableRAM_Connector (J1 uses Conn_02x25). Also moots an accidental
    CE2->CS2 pin rename that had landed in the dead ATF1502ASL. Library
    now holds only: AS6C8008, JTAG_Header, Jumper_1x02.
2026-06-12 Fix JTAG_Header symbol graphics
    The hand-built symbol had its body rectangle detached ~20mm from the
    pins, no background fill, and three degenerate zero-size rectangles.
    Redrawn: single body box enclosing the pin ends with standard
    background fill. Electrical pins unchanged (J2 connections intact).
    [PortableRAM-8MB.kicad_sch]
2026-06-12 Fix JP1 annotation: instance path must use root sheet UUID
    JP1's instances block used path "/" instead of the sheet UUID path,
    so KiCad displayed it as unannotated ("JP?").
    [PortableRAM-8MB.kicad_sch]
2026-06-12 Add section headers and on-sheet design notes
    Seven bold section titles (decode/control, transceivers, low/high
    byte arrays, size config, JTAG, connector) and a design-notes block
    documenting the memory map, BANKSEL, the WE-split rule, jumper
    semantics, CS2, DTACK policy, and the all-5V decision.
    [PortableRAM-8MB.kicad_sch]
2026-06-13 Group ERC power anchors: move GND PWR_FLAG beside the +5V one
    #FLG02 was stacked on a GND point under U2, where it read as part of
    the memory array. Both flags now sit together at the sheet corner
    (+5V anchor at 24.13,67.31, GND anchor at 30.48,67.31) as an explicit
    ERC-bookkeeping landmark. No electrical change.
    [PortableRAM-8MB.kicad_sch]
2026-06-13 Annotate the ERC power-anchor pair
    [PortableRAM-8MB.kicad_sch]
2026-06-13 PCB: strip all routing for fresh v2 layout, fix planes for all-5V
    Clean canvas: all tracks and vias deleted; B.Cu +5V pour removed
    (bottom layer freed for routing); In2 plane retargeted +3.3V -> +5V.
    Preserved: proven board outline + angled corner, J1 position, the
    edge-connector keepout, In1 GND plane, and all footprint placements
    as a starting point. Next: Update PCB from Schematic, re-place as
    needed, edge keepout, route.
    [PortableRAM-8MB.kicad_pcb]
2026-06-13 PCB: remove orphaned U10 (AMS1117) footprint
    The LDO left the schematic in the all-5V conversion; the In2 plane
    carries +5V directly, so v2 needs neither the part nor the v0.2
    bridge trick. Footprint deleted from the board.
    [PortableRAM-8MB.kicad_pcb]
2026-06-13 PCB: uniform SRAM orientation + silkscreen population guide
    - U3, U4, U9 rotated from 180 to 0: all eight SRAMs now face the same
    way (assembly-error prevention; free to do on the unrouted board)
    - Silkscreen: '4+8MB' under U2/U3/U6/U7, '8MB only' under U4/U5/U8/U9,
    plus a two-line legend tying population to the JP1 jumper setting
    [PortableRAM-8MB.kicad_pcb]
2026-06-13 PCB placement complete; WE net renamed WEL to match firmware
    - Update PCB from Schematic applied: full v2 netlist on pads
    (WEL/WEH/BANKSEL/SIZE8), JP1/R5/C18/C19 placed
    - All 100nF decouplers within 2.2-4.0mm of their power pins; all four
    CPLD VCC pins individually decoupled
    - Bulk caps cover both J1 VCC pin clusters plus two points inside the
    memory array
    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
    [PortableRAM-8MB.kicad_pcb]
2026-06-13 Add edge keepout rule areas before routing
    Five 0.6mm bands tracing inside the board outline (bottom, left,
    right, chamfer, sloped top) on all four copper layers, tracks and
    vias disallowed. Prevents the autorouter from hugging the edge —
    the /SD6 lesson from v0.2, applied before routing this time.
    [PortableRAM-8MB.kicad_pcb]
2026-06-13 PCB: power/ground stitching complete
    Every SMD power and ground pad via'd to its plane (In2=+5V, In1=GND):
    SRAM pins 11/12 plus the 33/34 anchor pads and the critical CS2 (pad
    40) active-high enable on all 8 chips, CPLD's 4+4 power pins, both
    '245s, and all 19 decoupling/bulk caps. DRC: 0 power/GND pads
    floating; only the 283 signal-net ratsnest remains for routing.
    [PortableRAM-8MB.kicad_pcb]
2026-06-13 PCB: BANKSEL hand-routed; footprints locked
    BANKSEL (CPLD pin 33 -> A19 on all 8 SRAMs) routed as a 4-spine
    fishbone on F.Cu; verified all 8 chips on one net. All 37 footprints
    locked. Track/via locking still pending (Ctrl+A caught footprints
    only — Selection Filter excluded tracks).
    [PortableRAM-8MB.kicad_pcb]
2026-06-13 PCB: lock all manual copper before routing
    All 220 power+BANKSEL segments and 69 stitching vias now locked (plus
    37 footprints). FreeRouting will import these as fixed and route the
    address/data buses around them.
    [PortableRAM-8MB.kicad_pcb]
2026-06-13 PCB: FreeRouting complete — fully routed, DRC clean
    Imported autorouted .ses (buses on F.Cu/B.Cu; inner layers stay pure
    GND/+5V planes). 3507 segments, 439 vias. DRC: 0 errors, 0 unconnected
    pads, 0 duplicate copper. All 220 locked power+BANKSEL segments and 69
    vias survived import unchanged. FreeRouting's ~30 "unrouted" were
    plane connections it can't see; resolved on zone refill (the v0.2
    lesson). Remaining 5 items all cosmetic silk/footprint-filter.
    [PortableRAM-4MB-Freerouter.dsn, PortableRAM-8MB.kicad_pcb]
2026-06-13 PCB: silk nudges + plot v2 fab package
    C14 and JP1 reference labels nudged clear of overlaps (silk_overlap
    and one silk_over_copper resolved). DRC now matches v0.2 accepted
    baseline: 0 unconnected, only inherent J1 silk/lib items + cosmetic
    footprint-filter notes. Plotted 11 Gerbers + PTH/NPTH drills, zipped.
    [PortableRAM-8MB.kicad_pcb]
2026-06-13 firmware: fix DIR polarity, drop AS/SLEEP gating (use UDS/LDS timing)
    Three logic fixes after verifying signal availability against Apple
    050-0219 and the proven miejas reference card:
    1. DIR was backwards. Board wires '245 A-side=bus, B-side=SRAM, so a
    read (RW=1) needs DIR low (B->A, SRAM->bus). Changed DIR = RW to
    DIR = !RW. Old value drove transceivers the wrong way every cycle.
    2. AS gating removed. AS* is not on the expansion connector (stays
    on-board feeding the refresh controller); CPLD pin 2 was pulled
    high, so "& AS" held every CE/OE/WE deasserted = dead card. Cycles
    now qualified by the data strobes (UDS*/LDS*), as the proven
    reference does. Pin 2 kept declared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
2026-06-13 Add v2 BOM (all-5V, AS6C8008, ASL CPLD)
    Ordering BOM: 8x AS6C8008-55 (1Mx8 5V), ATF1502ASL (5V CPLD, flagged
    NOT ASV), 2x 74HC245 wide-SOIC, Samtec J1, JTAG J2, SIZE jumper JP1
    (+shunt), 14x 100nF, 5x 10uF, 4x 10K. No LDO (single 5V domain).
    [PortableRAM-8MB-BOM.csv]
2026-06-14 BOM: correct AS6C8008 part# to -55ZIN (TSOP-II pkg), add price
    [PortableRAM-8MB-BOM.csv]
2026-06-14 Remove stale FreeRouting intermediates; gitignore *.dsn/*.ses
    The .dsn/.ses (mislabeled "4MB" from the v2 routing session) were
    committed early; routing now lives in the .kicad_pcb. Deleted and
    gitignored so they don't get re-tracked. Also removed stray DRC.rpt.
    [PortableRAM-4MB-Freerouter.dsn]
2026-06-18 firmware: generate .svf + Tigard/OpenOCD programming script
    - jed -> svf via fuseconv (whitequark/prjbureau), pure Python on the
    Mac (no Wine/ATMISP). PortableRAM8.svf self-verifies; ATF1502AS
    IR len 10, IDCODE 0x0150203f.
    - Added program.sh: one-command OpenOCD flash via Tigard (FT2232H)
    to J2 (TDI1/TMS7/TCK26/TDO32). Updated BUILD.md with both steps.
2026-07-03 v2 PCB: add TP1 ground test point on left edge for bench clip
    Left edge @ (71,125), clear of parts (11mm to nearest). 2.8mm pad /
    1.2mm plated hole on GND net -- alligator-clip target for bench
    ground / scope reference. Ground-only by choice (a 5V edge pad risks
    shorting; feed +5V via J2 pin 5 instead).
    Connects to In1 GND plane; 0 unconnected. The 2 clearance DRC items
    are stale-fill artifacts (In2 +5V plane needs to carve clearance
    around the new GND hole) -- clear on zone refill (B) in KiCad, done
    at the next re-plot before ordering.
    [PortableRAM-8MB.kicad_pcb]
2026-07-10 Bump to v2.0 — ready to order
    Fix SRAM part number AS6C8008-55TIN -> AS6C8008-55ZIN in all 8
    schematic instances (ZIN is the current TSOP-II-44 production part).
    Bump rev 2.0-dev -> 2.0 in PCB and schematic title blocks.
    v0.2 4MB card validated in hardware — gate cleared for v2 order.
    [PortableRAM-8MB.kicad_pcb, PortableRAM-8MB.kicad_sch]
2026-07-10 Apply v0.3 silkscreen improvements to v2: cap values on B.SilkS, J2 JTAG labels
    [PortableRAM-8MB.kicad_pcb]
2026-07-10 Add silkscreen population guide boxes — 4MB (JP1 CLOSED) and 8MB ONLY (JP1 OPEN)
    [PortableRAM-8MB.kicad_pcb]
2026-07-10 Regenerate Gerbers for v2.0 — cap silkscreen, J2 labels, population boxes, rev 2.0
    [PortableRAM-8MB-B_Cu.gbr, PortableRAM-8MB-B_Mask.gbr, PortableRAM-8MB-B_Paste.gbr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]
2026-07-10 Fix AS6C8008-55TIN -> 55ZIN in PCB value fields (7 instances missed earlier)
    [PortableRAM-8MB.kicad_pcb]
2026-07-10 Add Samtec BCS-125-F-D-HE part number to silkscreen above J1
    [PortableRAM-8MB.kicad_pcb]
2026-07-10 Fix gr_text missing UUID on J1 silkscreen label
    [PortableRAM-8MB.kicad_pcb]
2026-07-10 Remove invalid justify center from J1 silkscreen label
    [PortableRAM-8MB.kicad_pcb]
2026-07-10 Regenerate Gerbers — J1 part number silkscreen added
    [PortableRAM-8MB-B_Cu.gbr, PortableRAM-8MB-B_Mask.gbr, PortableRAM-8MB-B_Paste.gbr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]
2026-07-10 Add README with specs, assembly guide, cost breakdown, and bring-up notes
2026-07-10 Fix Gerbers output path to Gerbers/ subdir; adjust J1 silkscreen label position
    [PortableRAM-8MB.kicad_pcb]
2026-07-27 firmware: add CPLD /DTACK assertion via bodge wire to PDS B7 (rev 12)
    Pin 42 now drives /DTACK directly to the 68000 via a bodge wire from
    CPLD pin 42 to PDS slot pin B7. Pin 43 drives /EXT_DTACK (PDS B30,
    optional second wire). Both use tristate OE (active = ramsel & strobe)
    to avoid contention with the GLU on cycles not belonging to this card.
    Result: Speedometer 1.486 → 2.170, Snooper 51% → 102% on the 8MB card.
    Post-sleep collapse (was 22%) expected eliminated — combinatorial DTACK
    has no state to lose on wake.
2026-07-27 README: document DTACK bodge fix, benchmark results, hardware validation
    Replace pre-production warning with validated status. Replace the
    old sleep/wake bring-up note with a full DTACK Performance Fix section
    explaining the GLU wait-state problem, the combinatorial CPLD fix
    (pin 42 → PDS B7), and benchmark results showing Speedometer 1.486→2.170,
    Snooper 51%→102%, post-sleep collapse eliminated.
2026-07-27 Add hardware photos: About This Mac 9MB, installed card, DTACK bodge wire
2026-07-27 docs: add PDS slot photo with /DTACK (B7) location marked
    Annotated photo of Mac Portable logic board showing PDS connector
    (red) and RAM connector (blue) with /DTACK pin B7 called out.
2026-08-01 Add front and back photos of assembled v2 card with DTACK bodge wire
2026-08-01 Add component and solder side photos to README
